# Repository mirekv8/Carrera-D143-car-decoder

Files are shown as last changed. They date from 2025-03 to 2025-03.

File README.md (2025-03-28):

# Carrera D143 Car Decoder
Customized firmware for the Carrera Digital 143 decoder. The base is firmware from https://github.com/azya52/carrera. All functions work with CU 30352. 
Other features: 
-  Setting from CU 30352
-  Ghost car function
-  Front light support.
-  Break light support
-  Five custom speed curves are stored in EEPROM

  :100000000004000000FFFFFFFFFFFFFFFFFFFFFFF7<br/>
  :1000100000050A14191E23282D32373C46505A6E0B<br/>
  :10002000000A141F29333D47525C66707C858F9906<br/>
  :1000300000262E38414D555E67727C858E97A1B3A0<br/>
  :1000400000112233445566778899AABBCCDDEEFFB8<br/>
  :1000500000020D18232E39444F5A697D96AFD2FF06<br/>
  :10006000FFFFFFFFFFFFFFFFFFFFFFFFFFFFFFFFA0<br/>
  :10007000FFFFFFFFFFFFFFFFFFFFFFFF1004005325<br/>
  :00000001FF<br/>

-  A calibration value must be stored at 0x7f

# Calibration
A lot depends on calibration. I use https://github.com/felias-fogg/avrCalibrate for calibration. They set a calibration value of 1200000 not 1000000.

# Wiring
<p align="center">
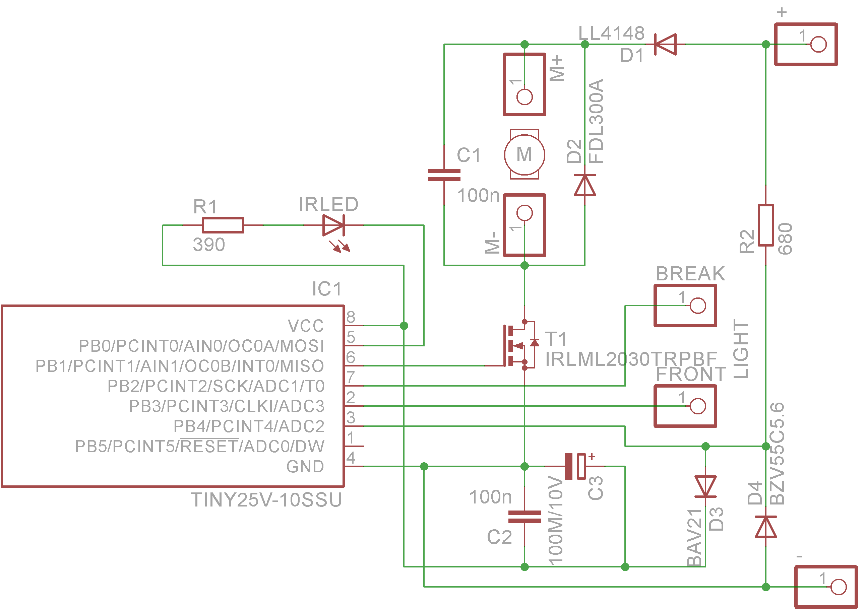
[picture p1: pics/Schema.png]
ATTINY25
  
</p>

# Speed curves
<p align="center">
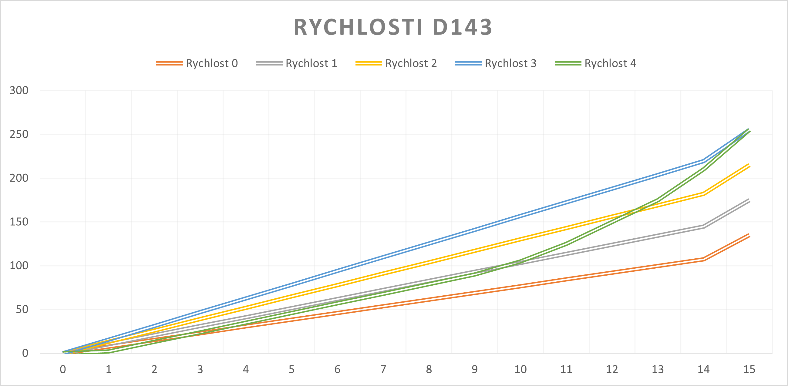
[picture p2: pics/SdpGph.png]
hover text
  
</p>

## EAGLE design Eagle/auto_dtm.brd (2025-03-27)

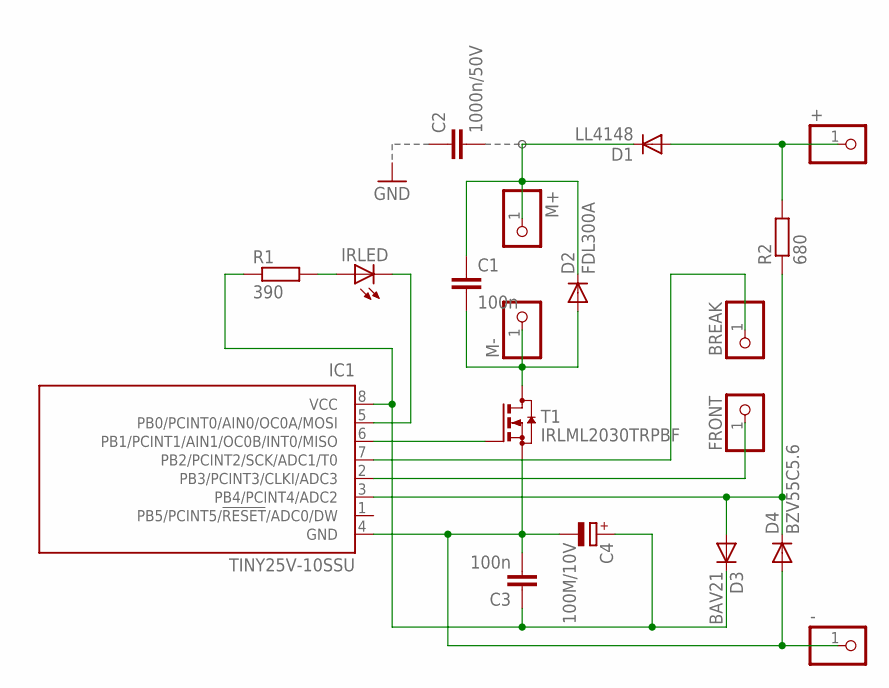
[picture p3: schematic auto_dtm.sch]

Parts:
+: PINHD-1X1; 1X01
-: PINHD-1X1; 1X01
BREAK: PINHD-1X1; 1X01
C1, C3: 100n; C1206
C2: 1000n/50V; C025-024X044
C4: 100M/10V; SMC_C
D1: LL4148; MINIMELF
D2: FDL300A; MINIMELF
D3: BAV21; MINIMELF
D4: BZV55C5.6; MINIMELF
FRONT: PINHD-1X1; 1X01
IC1: TINY25V-10SSU; 8S1
IRLED: LED3MM
M+: PINHD-1X1; 1X01
M-: PINHD-1X1; 1X01
R1: 390; R1206
R2: 680; R1206
T1: IRLML2030TRPBF; SOT23

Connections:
GND: -.1, C3.2, C4.-, D4.A, IC1.4 (GND), T1.2 (S)
unnamed: IC1.6 (PB1/PCINT1/AIN1/OC0B/INT0/MISO), T1.1 (G)
unnamed: C1.2, D2.A, M-.1, T1.3 (D)
unnamed: C1.1, D1.C, D2.C, M+.1
unnamed: IC1.5 (PB0/PCINT0/AIN0/OC0A/MOSI), IRLED.K (C)
unnamed: +.1, D1.A, R2.2
unnamed: IRLED.A, R1.2
unnamed: D3.A, D4.C, IC1.3 (PB4/PCINT4/ADC2), R2.1
unnamed: FRONT.1, IC1.2 (PB3/PCINT3/CLKI/ADC3)
unnamed: BREAK.1, IC1.7 (PB2/PCINT2/SCK/ADC1/T0)
VCC: C3.1, C4.+, D3.C, IC1.8 (VCC), R1.1

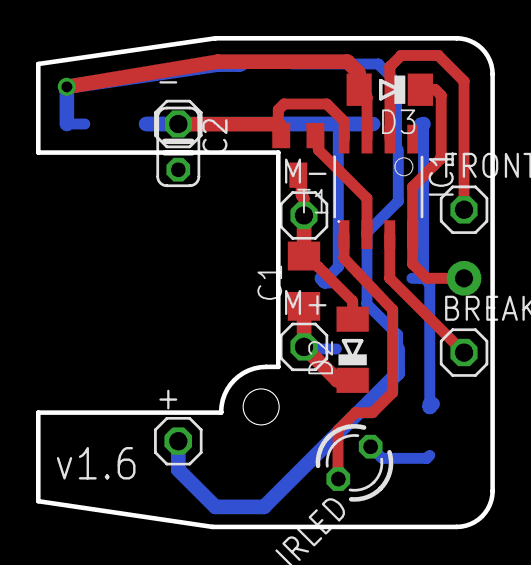
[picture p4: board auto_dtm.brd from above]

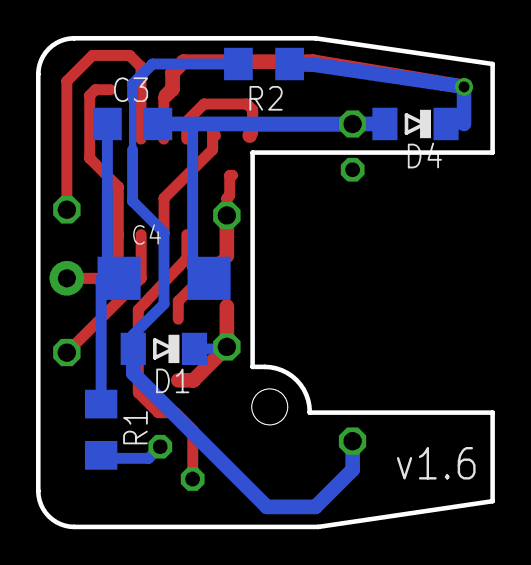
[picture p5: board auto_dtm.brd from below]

Board: 2 copper layers, 25.2 x 27.1 mm, 19 parts (6 on the bottom side), 11 nets.

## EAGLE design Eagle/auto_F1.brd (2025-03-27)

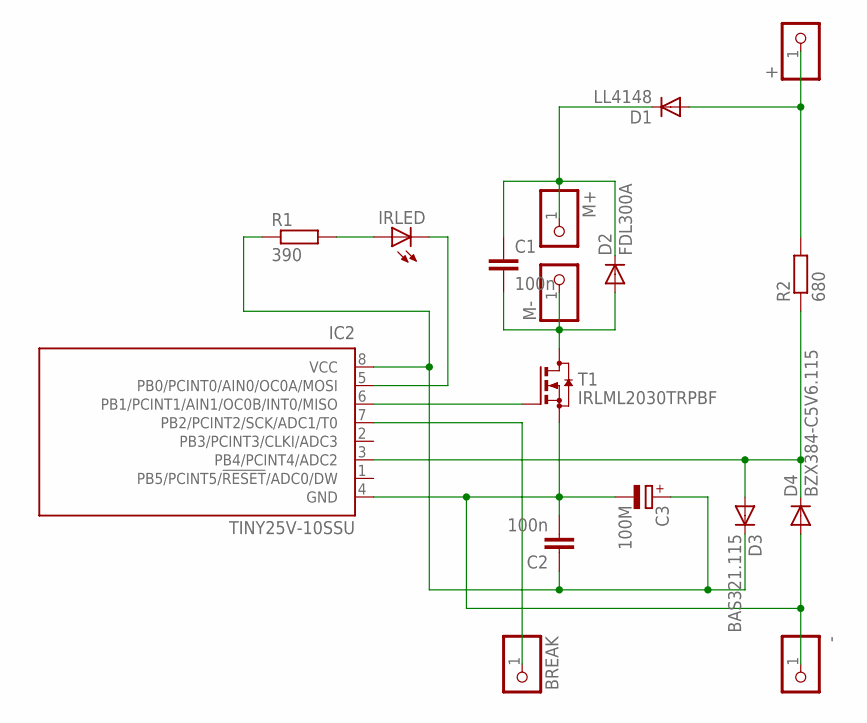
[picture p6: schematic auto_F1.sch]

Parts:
+: PINHD-1X1; 1X01
-: PINHD-1X1; 1X01
BREAK: PINHD-1X1; 1X01
C1, C2: 100n; C1206
C3: 100M; SMC_C
D1: LL4148; MINIMELF
D2: FDL300A; MINIMELF
D3: BAS321.115; MICROMELF-W
D4: BZX384-C5V6.115; MICROMELF-W
IC2: TINY25V-10SSU; 8S1
IRLED: LED3MM
M+: PINHD-1X1; 1X01
M-: PINHD-1X1; 1X01
R1: 390; R1206
R2: 680; R1206
T1: IRLML2030TRPBF; SOT23

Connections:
GND: -.1, C2.2, C3.-, D4.A, IC2.4 (GND), T1.2 (S)
unnamed: IC2.6 (PB1/PCINT1/AIN1/OC0B/INT0/MISO), T1.1 (G)
unnamed: C1.2, D2.A, M-.1, T1.3 (D)
unnamed: C1.1, D1.C, D2.C, M+.1
unnamed: IC2.5 (PB0/PCINT0/AIN0/OC0A/MOSI), IRLED.K (C)
unnamed: +.1, D1.A, R2.2
unnamed: IRLED.A, R1.2
unnamed: D3.A, D4.C, IC2.3 (PB4/PCINT4/ADC2), R2.1
unnamed: BREAK.1, IC2.7 (PB2/PCINT2/SCK/ADC1/T0)
VCC: C2.1, C3.+, D3.C, IC2.8 (VCC), R1.1

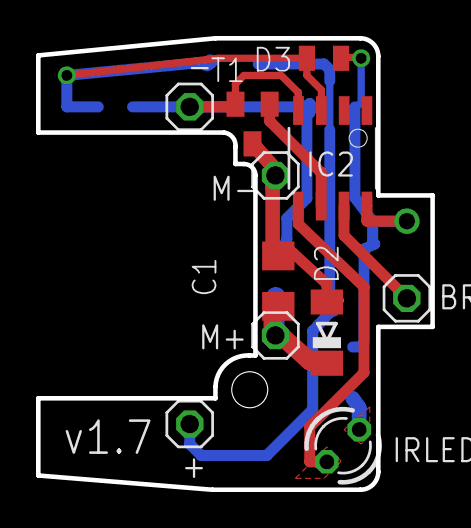
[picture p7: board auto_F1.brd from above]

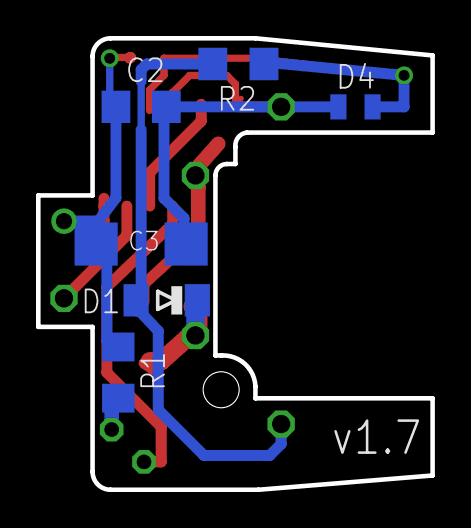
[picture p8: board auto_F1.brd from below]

Board: 2 copper layers, 21.9 x 25.1 mm, 17 parts (6 on the bottom side), 10 nets.

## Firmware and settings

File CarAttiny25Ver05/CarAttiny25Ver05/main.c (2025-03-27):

/*
 * CarAttiny25.c
 *
 * Created: 08.01.2018 15:27:24
 * Author : Alexander Zakharyan
 *
 * Revision: 31.10.2023 13:33:55
 * Author : Miroslav Vozar
 * 
 * - pøíkazy od CU 132/124
 * - 5 køivek rychlosti
 * - presna kalibrace OSCCAL v EEPROM na 0x7F
 */ 

#include <avr/io.h>
#include <util/delay.h>
#include <avr/interrupt.h>
#include <avr/eeprom.h>
#include <avr/sleep.h>
#include <avr/power.h>
#include <avr/pgmspace.h>

#define TRACK_PIN PB4
#define MOTOR_PIN PB1
#define IRLED_PIN PB0
#define FRONTLIGHT_PIN PB3
#define STOPLIGHT_PIN PB2
#define NU_PIN3 PB5

#define PACKET_PERIOD_MS 75
#define DBLCLICK_DELAY_MS 250
#define DBLCLICK_DELAY DBLCLICK_DELAY_MS/PACKET_PERIOD_MS
#define STOPBEFORELIGHT_DELAY_MS 3000
#define STOPBEFORELIGHT_DELAY STOPBEFORELIGHT_DELAY_MS/PACKET_PERIOD_MS
#define STOPLIGHT_DELAY_MS 500
#define STOPLIGHT_DELAY STOPLIGHT_DELAY_MS/PACKET_PERIOD_MS

#define TRANSM_FREQ 9800
#define PERIOD_QURT_CICLES F_CPU/TRANSM_FREQ/4

#define PROG_WORD_CHECK 12
#define CONTROLLER_WORD_CHECK 9
#define ACTIV_WORD_CHECK 7

#define GHOST_CAR_ID 6
#define PACE_CAR_ID 7

#define SHORT_TONE_MS 100
#define LONG_TONE_MS 200

#define MIN_CAR_SPEED_MULTIPLIER 0
#define MAX_CAR_SPEED_MULTIPLIER 4

uint8_t EEMEM eeprom_carID; 
uint8_t EEMEM eeprom_progInNextPowerOn; 
uint8_t EEMEM eeprom_ghostSpeed; 
uint8_t EEMEM eeprom_speedMultiplier; 
uint8_t EEMEM eeprom_lightOn;

uint8_t volatile carID = 255;
uint8_t volatile currentSpeed = 0;
uint8_t volatile sincWordIndex = 0;
uint8_t volatile doubleClickControllerId = 255;
uint8_t volatile countClickSW = 0;
uint8_t volatile notClickSWTime = 0;
uint8_t volatile progMode = 0;
uint8_t volatile progGhostMode = 0;
uint8_t volatile progSpeedMode = 0;
uint8_t volatile ghostSpeed = 0;
uint8_t volatile speedMultiplier = 4;
uint8_t volatile progSpeedSelecter = 0;
uint8_t volatile lightOn = 0;
uint8_t volatile stopTime = 0;
uint8_t volatile stopLightTime = 0;
uint8_t volatile lastSpeed = 0;
uint8_t volatile prgClickControllerId = 255;
uint8_t volatile prevSw = 0;
uint8_t volatile prgModeReady = 0;
uint8_t volatile countClickPrg = 0;
uint8_t volatile notClickPrg = 0;
uint8_t volatile codeGhostMode = 0;

uint8_t volatile fuel = 0;
uint16_t volatile oldProgDataWord = 0;
uint8_t eeprom_speed[16];

const uint8_t swapByte[] PROGMEM = {0b00000000,	0b00001000, 0b00000100, 0b00001100, 0b00000010, 0b00001010,	0b00000110, 0b00001110,
0b00000001, 0b00001001, 0b00000101, 0b00001101, 0b00000011, 0b00001011, 0b00000111,	0b00001111};

const uint8_t speedValue[] PROGMEM = {0, 0, 0, 1, 1, 1, 2, 2, 2, 3, 3, 3, 4, 4, 4, 4};

void playTone() {
	cli();
	TCCR0B = (0 << WGM02) | (1 << CS01) | (1 << CS00); // dìleno 64
	OCR0B = 240;
	_delay_ms(150);	
	OCR0B = 255;
	TCCR0B = (0 << WGM02) | (1 << CS00); // nedìleno 1:1
	sei();
}

void timersInit() {
	// MOTOR PWM
	TCCR0A = (1 << COM0B0) | (1 << COM0B1) | (3 << WGM00);
	TCCR0B = (0 << WGM02) | (1 << CS00); // nedìleno 1:1
	OCR0B = 255;

	// LED PWM
	TCCR1 |= (1 << CTC1) | (1 << PWM1A) | (1 << COM1A0) | (1 << CS12) | (1 << CS10); // dìleno 16
}

void startLEDPWM() {
	OCR1C = 32 * (carID + 1);
	OCR1A = OCR1C - 16;
}

void pinsInit() {
	DDRB = (1 << MOTOR_PIN) | (1 << IRLED_PIN) | (1 << FRONTLIGHT_PIN) | (1 << STOPLIGHT_PIN); //piny nastaveny jako výstupy
	
	PORTB = (1 << TRACK_PIN); //PullUp na pin TRACK
	PORTB |= (1 << NU_PIN3); //PullUp na nepoužité piny
}

void interruptsInit() {
	GIMSK = (1 << PCIE); //pøerušení PCINT
	MCUCR = (1 << ISC01) | (0 << ISC00); // sestupná hrana
	PCMSK = (1 << TRACK_PIN); //pøerušení pouze od pinu TRACK
	sei();
}

void setEepromSpeed(uint8_t speed) {
	switch (speed)
	{
		case 0:
			eeprom_read_block((void*)&eeprom_speed,(const void*)0x10,0x10);
		break;
		case 1:
			eeprom_read_block((void*)&eeprom_speed,(const void*)0x20,0x10);
		break;
		case 2:
			eeprom_read_block((void*)&eeprom_speed,(const void*)0x30,0x10);
		break;
		case 3:
			eeprom_read_block((void*)&eeprom_speed,(const void*)0x40,0x10);
		break;
		case 4:
			eeprom_read_block((void*)&eeprom_speed,(const void*)0x50,0x10);
		break;
	}
}

void setCarSpeed(uint8_t speed) {
	uint8_t actualSpeed;
	if (speed > 0) {
		codeGhostMode = 0;	
	}
	currentSpeed = speed;
	actualSpeed = eeprom_speed[speed];	
	OCR0B = 255 - actualSpeed + ((fuel * actualSpeed)>>7);
//	OCR0B = 255 - actualSpeed;	

}

void setCarID(uint8_t newId) {
	carID = newId;
	eeprom_write_byte(&eeprom_carID, newId);
	startLEDPWM();
}

void calcStopTime(uint8_t speed) {
	if (speed == 0) {
		if (stopTime < 255) {
			stopTime++;
		}
	} else {
		stopTime = 0;
	}
}

void setLights() {
	PORTB &= ~((1 << FRONTLIGHT_PIN) | (1 << STOPLIGHT_PIN));
	PORTB |= (lightOn & ((1 << FRONTLIGHT_PIN) | (1 << STOPLIGHT_PIN)));
}

void blinkLights() {
	PORTB ^= (1 << FRONTLIGHT_PIN);	
}

void switchFrontLight() {
	stopTime = STOPBEFORELIGHT_DELAY - DBLCLICK_DELAY;
	lightOn = ~lightOn;
	eeprom_write_byte(&eeprom_lightOn, lightOn);
	setLights();
}

void calcStopLightTime(uint8_t speed) {
	if (lastSpeed - speed > 2) {
		stopLightTime = STOPLIGHT_DELAY;
		setLights();
	} else {
		if (stopLightTime > 0) {
			stopLightTime--;
		}
	}
}

void stopLightMiddleOn() {
	if (lightOn && (stopLightTime == 0)) {
		PORTB ^= (1 << STOPLIGHT_PIN);
	}
}

void stopProg() {
	if (progSpeedMode) {
		speedMultiplier = progSpeedSelecter;
		progSpeedMode = 0;
		eeprom_write_byte(&eeprom_speedMultiplier, speedMultiplier);	
		setEepromSpeed(speedMultiplier);		
	}
	progMode = 0;
}

void onMultiClick(uint8_t controllerId, uint8_t clickCount) {
	if (progGhostMode) {
		ghostSpeed = currentSpeed;
		currentSpeed = 0;
		progGhostMode = 0;
		progMode = 0;
		eeprom_write_byte(&eeprom_ghostSpeed, ghostSpeed);
		setCarID(GHOST_CAR_ID);
		playTone();
	} else if (progSpeedMode) {
		playTone();
		progSpeedSelecter++;
		if (progSpeedSelecter == 4) {
			_delay_ms(50);
			playTone();
			stopProg();
		}
	} else if ((clickCount > 1) && (currentSpeed == 0)) {
		if (progMode) {
			playTone();			
			if (clickCount == 2) {
				if (codeGhostMode == 0) {
					codeGhostMode = 1;			
					setCarID(controllerId);
				}else {
					codeGhostMode = 0;
					carID = controllerId;
					progGhostMode = 1;					
				}
			} else if (clickCount == 3) {
				progSpeedMode = 1;
				progSpeedSelecter = 0;
				codeGhostMode = 0;				
			} else if (clickCount == 4 ) {
				carID = controllerId;
				progGhostMode = 1;
				codeGhostMode = 0;
			} else {
				progMode = 0;
			}
		}
	}
}


void checkPrgMode(uint8_t controllerId, uint8_t sw) {
	if((prgModeReady == 0)  && (progMode == 0)){		
		if(sw) { //není stisknuto
			if(controllerId == prgClickControllerId)
			{
				prevSw=0;
				if (notClickPrg++ > DBLCLICK_DELAY) {
					prgClickControllerId = 255;
				}								
			}
		} else { //je stisknuto
			notClickPrg = 0;
			if(!prevSw) { //nebylo stisknuto
				if (controllerId < prgClickControllerId) { //jde o první stisknutí
					prgClickControllerId = controllerId;
					countClickPrg = 0;
				}
				if ((controllerId == prgClickControllerId) && (currentSpeed == 0))  { // jde o další stisknutí
					prevSw=1;
					if(++countClickPrg > 1) { // dvojklik - programovací mod
						eeprom_write_byte(&eeprom_progInNextPowerOn, 1);
						playTone();						
						prgModeReady = 1;
						prevSw=0;
					}
				}
			}
		}
	}
}

void checkDblClick(uint8_t controllerId, uint8_t sw) {
	if (sw) { //not pressed
		if (controllerId == doubleClickControllerId) {
			if (notClickSWTime == 0) {
				countClickSW++;
			}
			if (notClickSWTime++ > DBLCLICK_DELAY) {
				doubleClickControllerId = 255;
				if (countClickSW > 0) {
					onMultiClick(controllerId, countClickSW);
				}
			}
		}
	} else {
		if (controllerId < doubleClickControllerId) {
			doubleClickControllerId = controllerId;
			countClickSW = 0;
		}
		if (doubleClickControllerId == controllerId) {
			notClickSWTime = 0;
		}
	}
}

void onProgramDataWordReceived(uint16_t word) {
	uint8_t addr = pgm_read_byte(&(swapByte[(word) & 0x0f])) >> 1;
	uint8_t command = (word >> 3) & 0x1f;
	uint8_t value = pgm_read_byte(&(swapByte[(word >> 8) & 0x0f]));
		
	if(addr == carID)
	{
		if(word == oldProgDataWord)
		{
			if (command == 0)
			{
				playTone();
				speedMultiplier = pgm_read_byte(&(speedValue[value]));
				eeprom_update_byte(&eeprom_speedMultiplier, speedMultiplier);
				setEepromSpeed(speedMultiplier);
			}
		}
		if (command == 4)
		{
			fuel = value & 0x07;
		}
	}
	oldProgDataWord=word;
}

void onActiveControllerWordReceived(uint16_t word) {
	uint8_t parity = word & 0xFE;
	parity = parity ^ (parity >> 4);
	parity ^= parity >> 2;
	parity ^= parity >> 1;
	parity &= 0x01;
	if (parity == (word & 0x01)) {
		return;
	}
	
	uint8_t anyKeyPressed = word & 0x7F;
	if (anyKeyPressed) {
		stopProg();
	}
	
	uint8_t currentKeyPressed = (word << (carID & 0x0F)) & 0x40;
	if (carID == GHOST_CAR_ID) {
		if ((currentSpeed == 0) && anyKeyPressed) {
			setCarSpeed(ghostSpeed);
		}
	} else {
		if (currentKeyPressed) {
			if (currentSpeed == 0) {
				setCarSpeed(1);
			}
		} else {
			setCarSpeed(0);
		}
	}
}

void onControllerWordReceived(uint16_t word) {
	uint8_t controllerId = (word >> 6) & 0x07;
	uint8_t speed = (word >> 1) & 0x0F;
	uint8_t sw = (word >> 5) & 1;
	checkPrgMode(controllerId, sw);	
	if (controllerId == carID) {
		setCarSpeed(speed);
		calcStopTime(speed);
		calcStopLightTime(speed);
		if (!sw && (stopTime > STOPBEFORELIGHT_DELAY) && !progMode) {
			switchFrontLight();
		}
		lastSpeed = speed;
	} 
	checkDblClick(controllerId, sw);
}

void onWordReceived(uint16_t word) {
	stopLightMiddleOn();
	if ((word >> PROG_WORD_CHECK) == 1) {
		onProgramDataWordReceived(word);
	} else
	if ((word >> CONTROLLER_WORD_CHECK) == 1) {
		if ((word >> 6) != 0x0F) {
			onControllerWordReceived(word);
		}
	} else
	if ((word >> ACTIV_WORD_CHECK) == 1) {
		onActiveControllerWordReceived(word);
	}
}

ISR(PCINT0_vect) {
	uint8_t start = TCNT0;
	while ((uint8_t) (TCNT0 - start) < PERIOD_QURT_CICLES);
	start += PERIOD_QURT_CICLES;
	uint8_t firstHalfCycle = 1;
	uint8_t secondHalfCycle = 0;
	uint16_t receivedValue = 0;
	while (firstHalfCycle != secondHalfCycle) {
		receivedValue = (receivedValue << 1) | firstHalfCycle;

		while ((uint8_t) (TCNT0 - start) < PERIOD_QURT_CICLES);
		start += PERIOD_QURT_CICLES;
		while ((uint8_t) (TCNT0 - start) < PERIOD_QURT_CICLES);
		start += PERIOD_QURT_CICLES;

		firstHalfCycle = (PINB >> TRACK_PIN) & 1;

		while ((uint8_t) (TCNT0 - start) < PERIOD_QURT_CICLES);
		start += PERIOD_QURT_CICLES;
		while ((uint8_t) (TCNT0 - start) < PERIOD_QURT_CICLES);
		start += PERIOD_QURT_CICLES;
		
		secondHalfCycle = (PINB >> TRACK_PIN) & 1;
	}
	onWordReceived(receivedValue);
	GIFR = 1 << PCIF;
}


int main(void) {
	OSCCAL=eeprom_read_byte((const void*)0x7f);
    carID = eeprom_read_byte(&eeprom_carID);
	ghostSpeed = eeprom_read_byte(&eeprom_ghostSpeed);
	speedMultiplier = eeprom_read_byte(&eeprom_speedMultiplier);
	if (speedMultiplier > MAX_CAR_SPEED_MULTIPLIER) {
		speedMultiplier = MAX_CAR_SPEED_MULTIPLIER;
	}
	setEepromSpeed(speedMultiplier);
	progMode = eeprom_read_byte(&eeprom_progInNextPowerOn);
	if (progMode) {
		if (progMode > 1) {
			progMode = 0;
		}
		eeprom_write_byte(&eeprom_progInNextPowerOn, 0);	
	}
	lightOn = eeprom_read_byte(&eeprom_lightOn);
	
	power_adc_disable();
	power_usi_disable();
	//ADCSRA = 0; //disable the ADC

	pinsInit();
	timersInit();
	startLEDPWM();
	setLights();
	interruptsInit();
	
	set_sleep_mode(SLEEP_MODE_IDLE);
	while (1) {
		sleep_enable(); 
		sleep_cpu(); 
	}
}
